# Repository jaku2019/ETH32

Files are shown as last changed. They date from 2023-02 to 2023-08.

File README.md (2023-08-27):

# Supla powered ETH32 light coontroller
Thanks to the amazing help of @elmaya @radzik_r @klew and othher forum.supla.org users I managed to create ETH32 light controller.

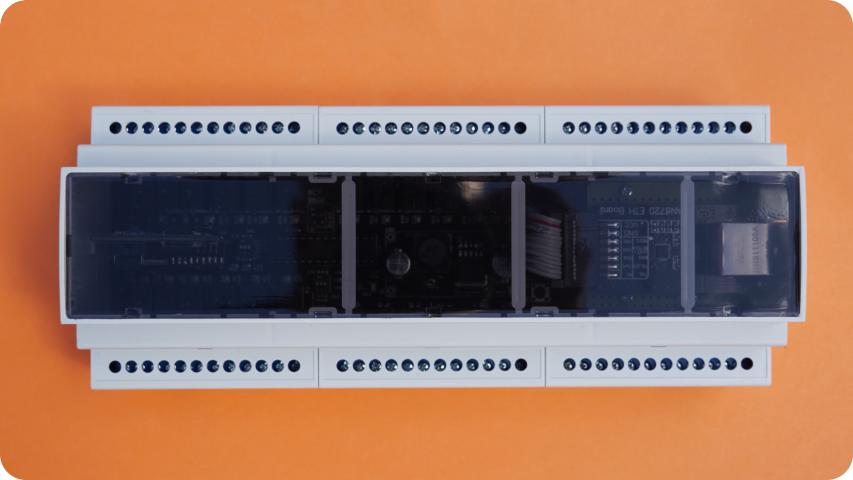
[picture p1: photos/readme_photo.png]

## Main characteristics
- 17 230V inputs (in the photo sample: 16x230V 1x12V) [PC814]
- 18 230V 5A inputs [HF46F/12V]
- TEST button that turns on all the relays (you can change that function in the code)
- LAN8721
- 2xMCP23017 (there is a possibility to channge its addresses with DIN switches)
- easy-access pins: 3,3V, 5V, GND, IO12, IO15, IO35, IO36, IO39, IO0, RX, TX
- easy access to I2C pins
- MCP9808 temperature sensor (there is a possibility to channge its address with DIN switch)
- RTC clock DS3231
- FRAM memory MB85RC256V (there is a possibility to channge its address with DIN switch)

## Info
Instead of soldering the buck converter elements to the PCB, you can insert a ready module LM2596 (it is necessary to set its output voltage to 5V)

ESP is connected with IO by MCP23017. One of this modules was placed on a card that is a bit loose. You shouldn't play with it when ETH32 is on, as it could make the relays stop working. Repositioning it to 90 degrees should solve the problem.

The PCB is designed to fit perfectly in the Kradex ZD1012 enclosure for DIN rail.
## The code
In the software example relays no. 101-116 have assigned inputs with relative numbers. 

Input no. 117 turns on all the relays.
Single click = turn on (all),
double click = turn off (all). 

Everything is preperad to work with monostable buttons. 

There is no thermometer, FRAM memory nor RTC support yet.
## Smart home control
You need to set your Supla accunt mail and server address in the coode (relative fields are placed in the bottom of the code).

You can integrate Supla with e.g. Home Assistant via MQTT. The setup is pretty easy and reliable. https://en-forum.supla.org/viewtopic.php?t=10419

## On the din rail
And that's how it ended! 

You can download a Word file, where you can find ready labels to stick on the enclosure.
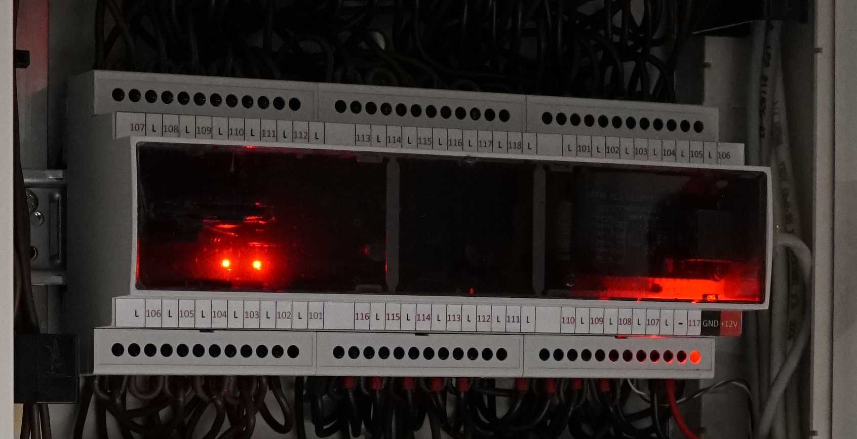
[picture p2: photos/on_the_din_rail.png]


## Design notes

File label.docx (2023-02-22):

| 107 | L | 108 | L | 109 | L | 110 | L | 111 | L | 112 | L | | 113 | L | 114 | L | 115 | L | 116 | L | 117 | L | 118 | L | | L | 101 | L | 102 | L | 103 | L | 104 | L | 105 | L | 106

| L | 106 | L | 105 | L | 104 | L | 103 | L | 102 | L | 101 | | 116 | L | 115 | L | 114 | L | 113 | L | 112 | L | 111 | L | | 110 | L | 109 | L | 108 | L | 107 | L | - | 117 | GND | +12V

| 207 | L | 208 | L | 209 | L | 210 | L | 211 | L | 212 | L | | 213 | L | 214 | L | 215 | L | 216 | L | 217 | L | 218 | L | | L | 201 | L | 202 | L | 203 | L | 204 | L | 205 | L | 206

| L | 206 | L | 205 | L | 204 | L | 203 | L | 202 | L | 201 | | 216 | L | 215 | L | 214 | L | 213 | L | 212 | L | 211 | L | | 210 | L | 209 | L | 208 | L | 207 | L | - | 217 | GND | +12V

| 107 | L | 108 | L | 109 | L | 110 | L | 111 | L | 112 | L | | 113 | L | 114 | L | 115 | L | 116 | L | 117 | L | 118 | L | | L | 101 | L | 102 | L | 103 | L | 104 | L | 105 | L | 106

| L | 106 | L | 105 | L | 104 | L | 103 | L | 102 | L | 101 | | 116 | L | 115 | L | 114 | L | 113 | L | 112 | L | 111 | L | | 110 | L | 109 | L | 108 | L | 107 | L | - | 117 | GND | +12V

| 207 | L | 208 | L | 209 | L | 210 | L | 211 | L | 212 | L | | 213 | L | 214 | L | 215 | L | 216 | L | 217 | L | 218 | L | | L | 201 | L | 202 | L | 203 | L | 204 | L | 205 | L | 206

| L | 206 | L | 205 | L | 204 | L | 203 | L | 202 | L | 201 | | 216 | L | 215 | L | 214 | L | 213 | L | 212 | L | 211 | L | | 210 | L | 209 | L | 208 | L | 207 | L | - | 217 | GND | +12V

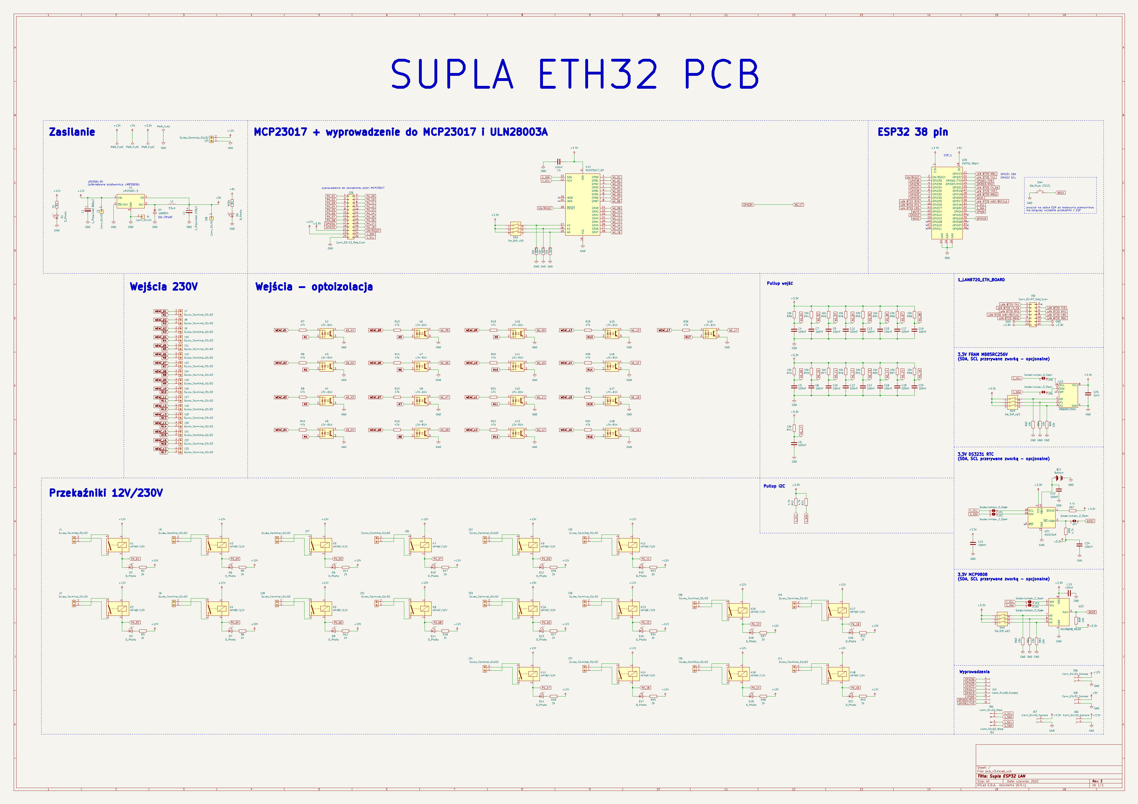
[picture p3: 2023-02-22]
photos/schematic.png

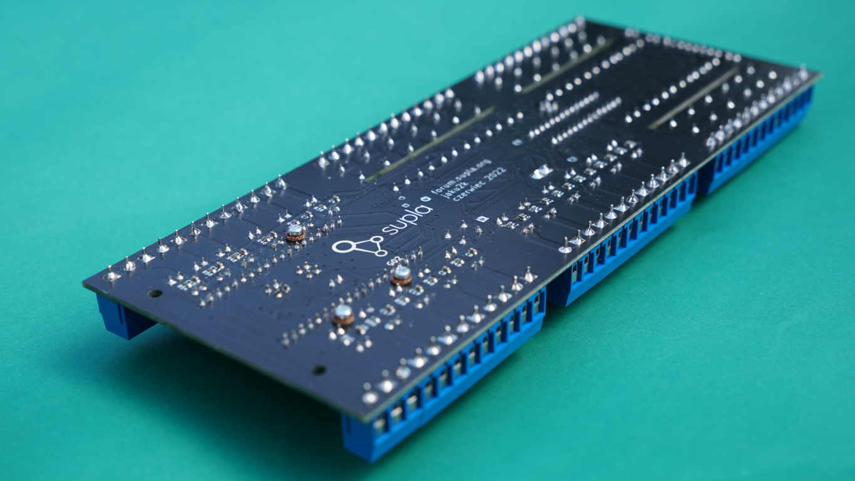
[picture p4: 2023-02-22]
photos/ETH32_photo (9).png

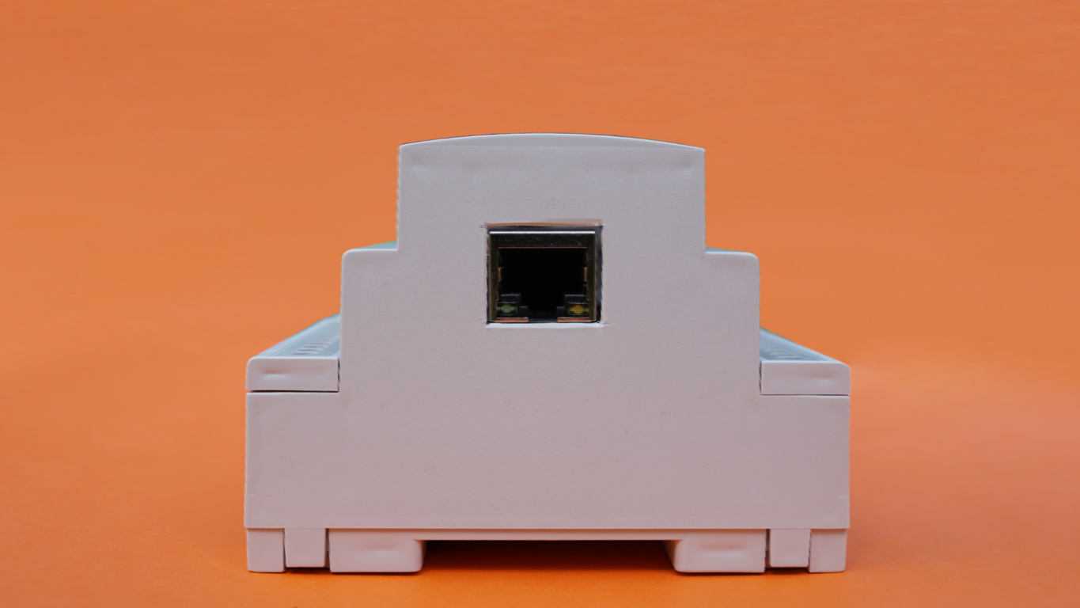
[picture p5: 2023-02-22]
photos/ETH32_photo (5).png

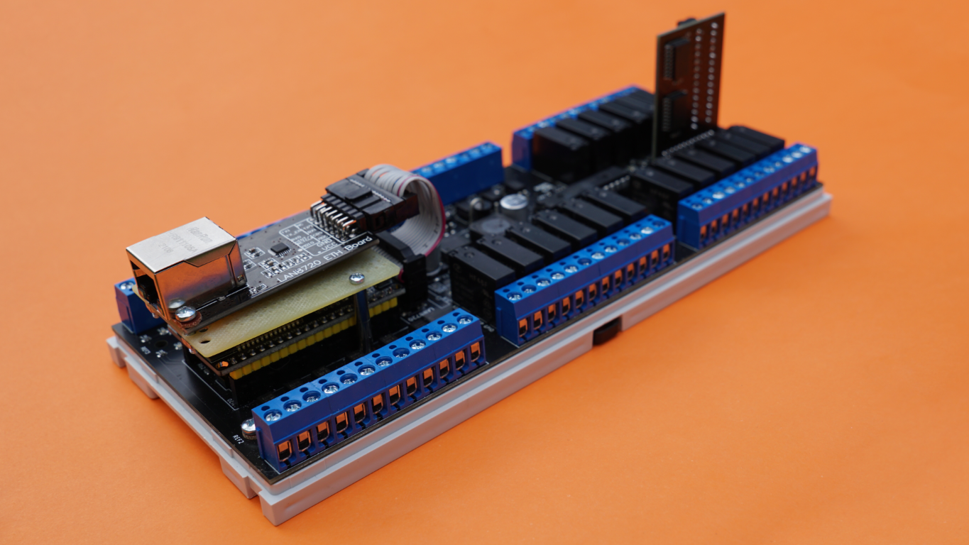
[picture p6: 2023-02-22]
photos/ETH32_photo (1).png

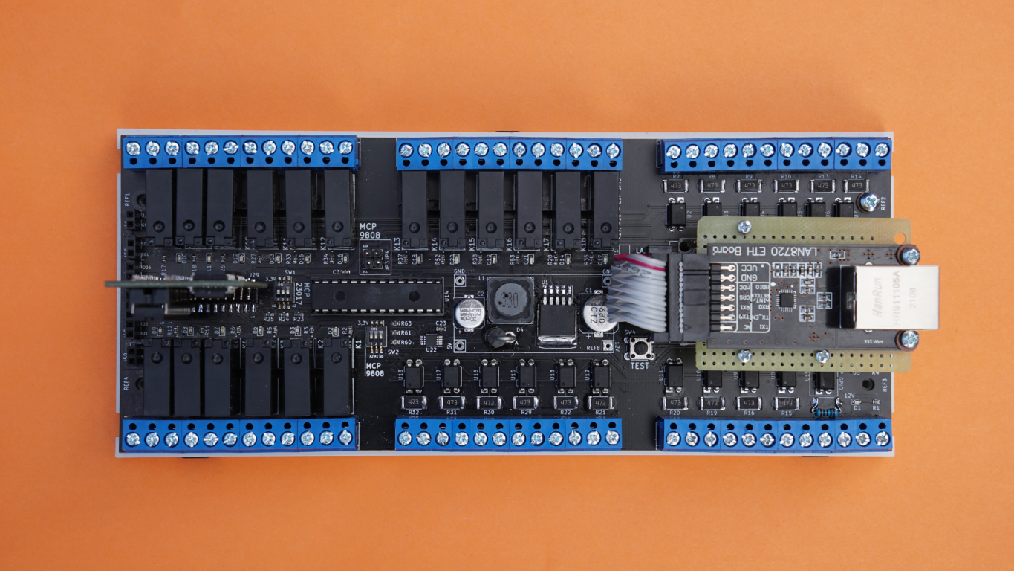
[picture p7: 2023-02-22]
photos/ETH32_photo (3).png

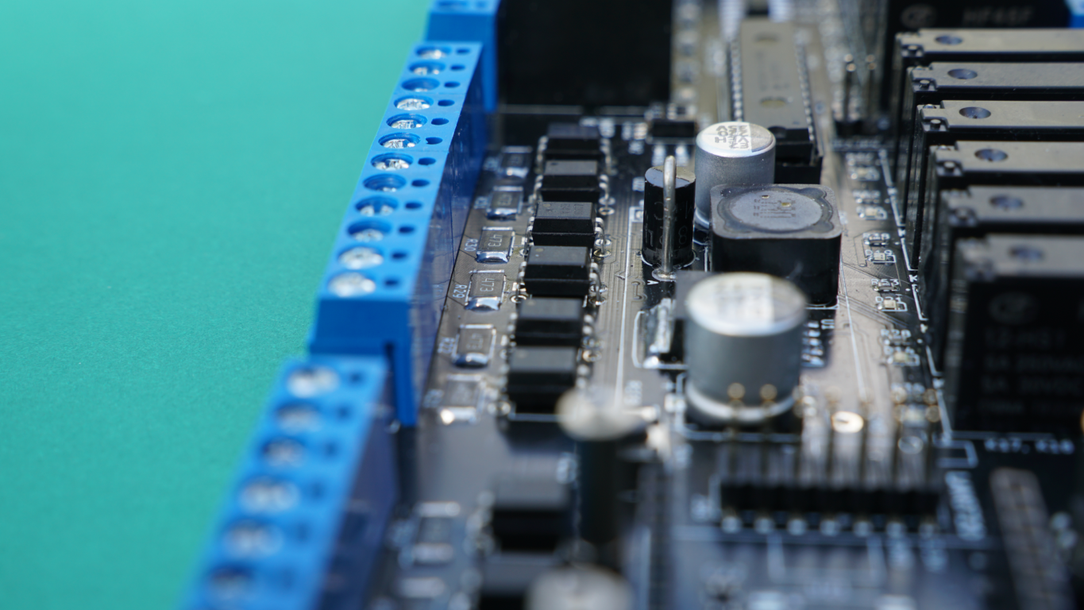
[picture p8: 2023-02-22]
photos/ETH32_photo (10).png

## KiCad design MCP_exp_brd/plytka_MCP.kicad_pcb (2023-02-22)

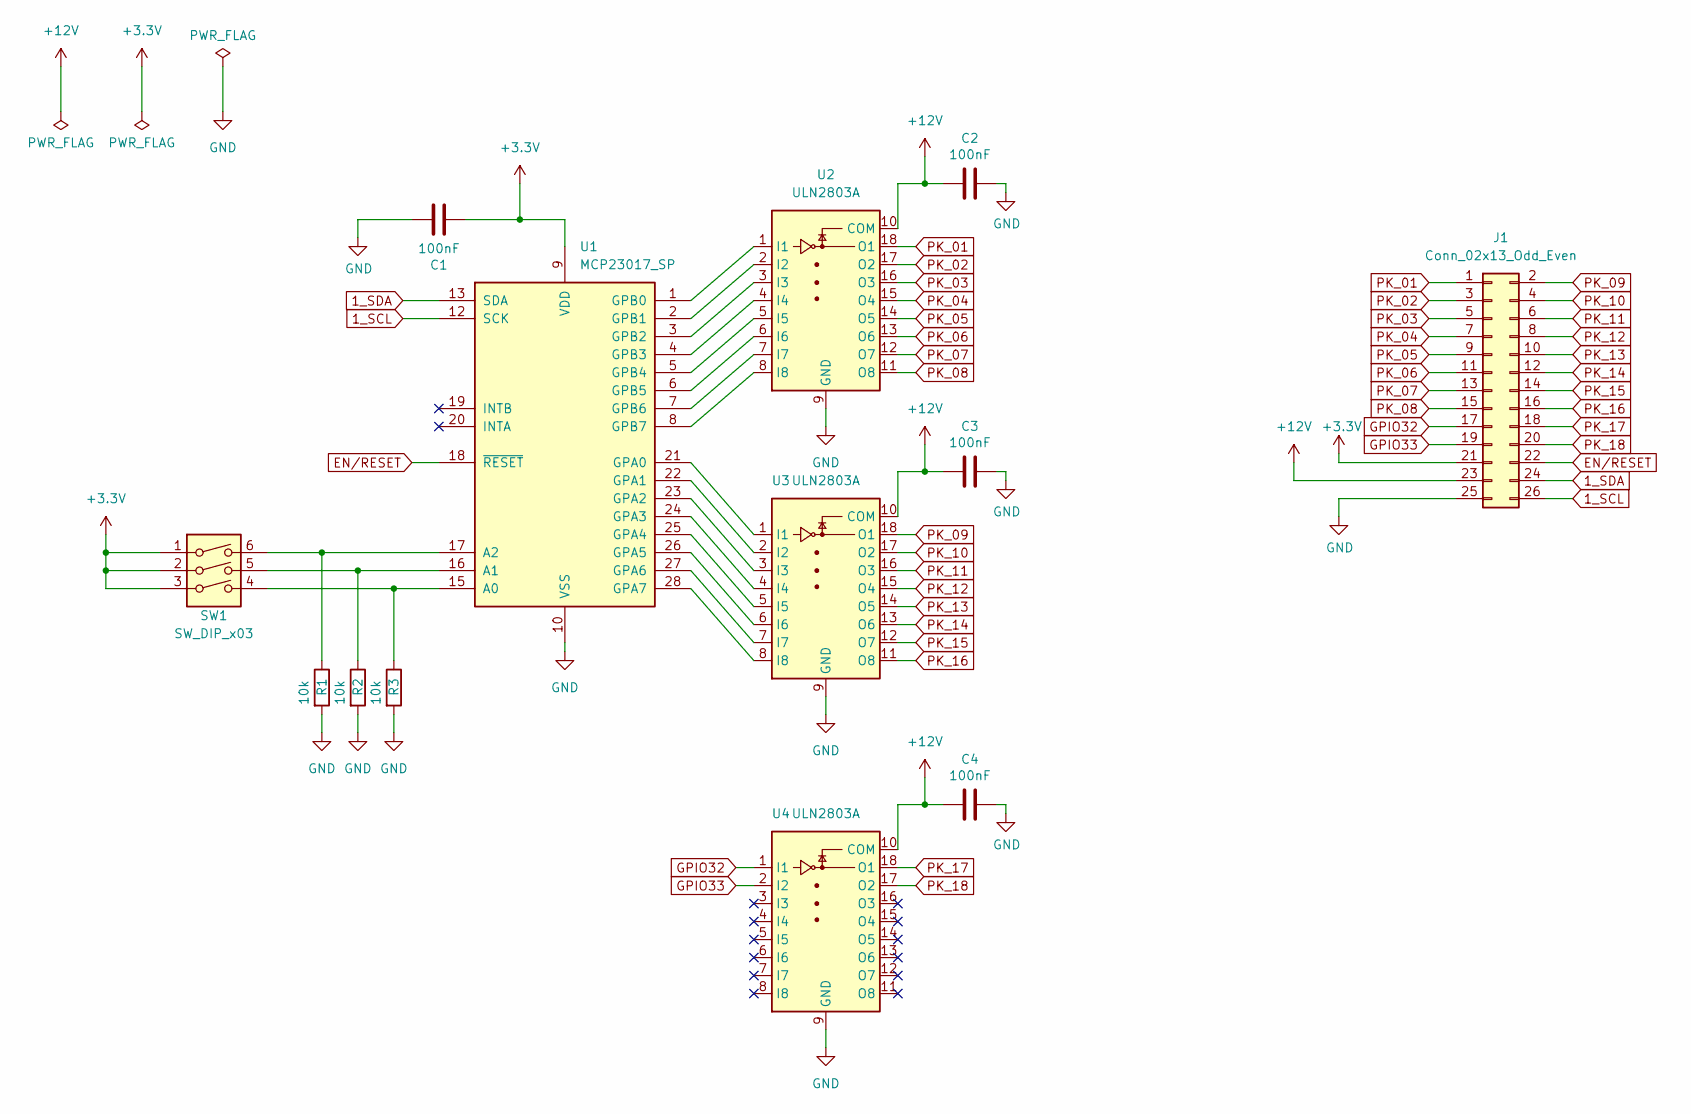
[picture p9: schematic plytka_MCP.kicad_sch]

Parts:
C1, C2, C3, C4: 100nF; C_0603_1608Metric; JLCPCB C14663
J1: Conn_02x13_Odd_Even; PinHeader_2x13_P2.00mm_Horizontal; JLCPCB C2883270
R1, R2, R3: 10k; R_0603_1608Metric; JLCPCB C238881
SW1: SW_DIP_x03; SW_DIP_SPSTx03_Slide_KingTek_DSHP03TS_W7.62mm_P1.27mm; JLCPCB C319051
U1: MCP23017_SP; DIP-28_W7.62mm_Socket; JLCPCB C16653
U2, U3, U4: ULN2803A; SOIC-18W_7.5x11.6mm_P1.27mm; JLCPCB C845537

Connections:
1_SCL: J1.26, U1.12 (SCK)
1_SDA: J1.24, U1.13 (SDA)
+3V3: C1.2, J1.21, SW1.1, SW1.2, SW1.3, U1.9 (VDD)
+12V: C2.2, C3.2, C4.2, J1.23, U2.10 (COM), U3.10 (COM), U4.10 (COM)
EN/RESET: J1.22, U1.18 (~RESET)
GND: C1.1, C2.1, C3.1, C4.1, J1.25, R1.2, R2.2, R3.2, U1.10 (VSS), U2.9 (GND), U3.9 (GND), U4.9 (GND)
GPIO32: J1.17, U4.1 (I1)
GPIO33: J1.19, U4.2 (I2)
unnamed: R1.1, SW1.6, U1.17 (A2)
unnamed: R2.1, SW1.5, U1.16 (A1)
unnamed: R3.1, SW1.4, U1.15 (A0)
unnamed: U1.1 (GPB0), U2.1 (I1)
unnamed: U1.2 (GPB1), U2.2 (I2)
unnamed: U1.3 (GPB2), U2.3 (I3)
unnamed: U1.4 (GPB3), U2.4 (I4)
unnamed: U1.5 (GPB4), U2.5 (I5)
unnamed: U1.6 (GPB5), U2.6 (I6)
unnamed: U1.7 (GPB6), U2.7 (I7)
unnamed: U1.8 (GPB7), U2.8 (I8)
unnamed: U1.21 (GPA0), U3.1 (I1)
unnamed: U1.22 (GPA1), U3.2 (I2)
unnamed: U1.23 (GPA2), U3.3 (I3)
unnamed: U1.24 (GPA3), U3.4 (I4)
unnamed: U1.25 (GPA4), U3.5 (I5)
unnamed: U1.26 (GPA5), U3.6 (I6)
unnamed: U1.27 (GPA6), U3.7 (I7)
unnamed: U1.28 (GPA7), U3.8 (I8)
PK_01: J1.1, U2.18 (O1)
PK_02: J1.3, U2.17 (O2)
PK_03: J1.5, U2.16 (O3)
PK_04: J1.7, U2.15 (O4)
PK_05: J1.9, U2.14 (O5)
PK_06: J1.11, U2.13 (O6)
PK_07: J1.13, U2.12 (O7)
PK_08: J1.15, U2.11 (O8)
PK_09: J1.2, U3.18 (O1)
PK_10: J1.4, U3.17 (O2)
PK_11: J1.6, U3.16 (O3)
PK_12: J1.8, U3.15 (O4)
PK_13: J1.10, U3.14 (O5)
PK_14: J1.12, U3.13 (O6)
PK_15: J1.14, U3.12 (O7)
PK_16: J1.16, U3.11 (O8)
PK_17: J1.18, U4.18 (O1)
PK_18: J1.20, U4.17 (O2)

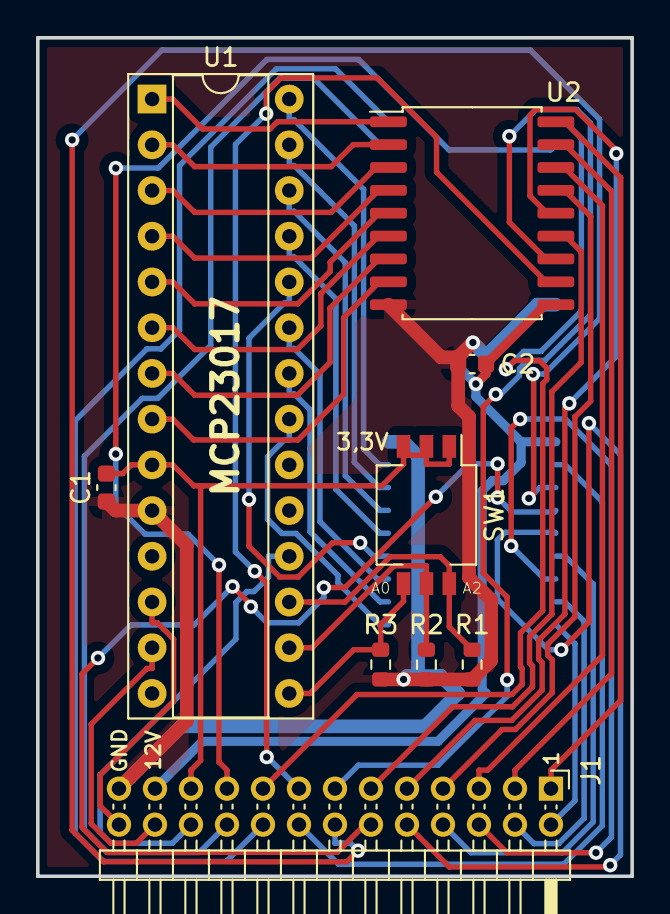
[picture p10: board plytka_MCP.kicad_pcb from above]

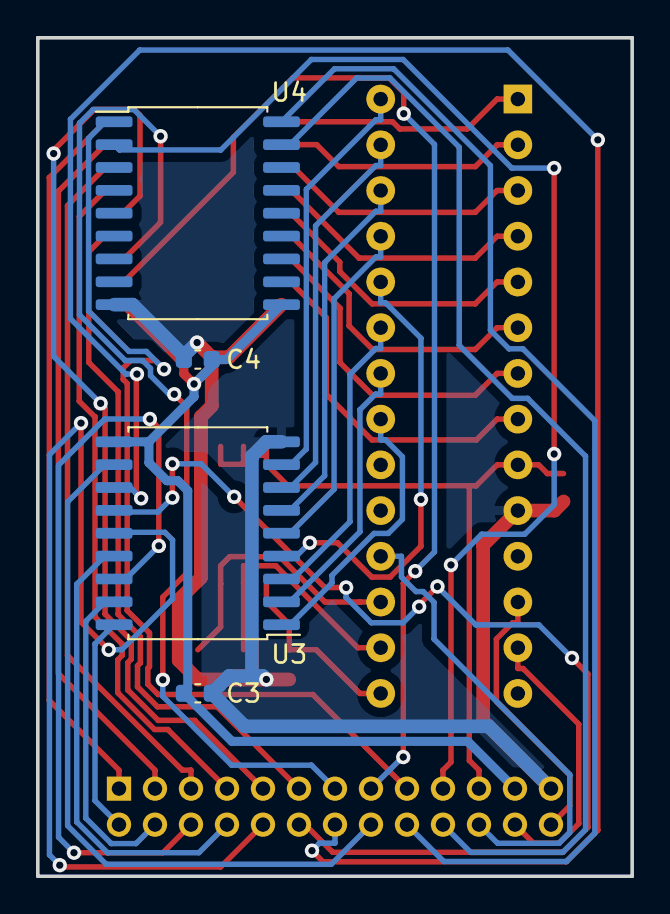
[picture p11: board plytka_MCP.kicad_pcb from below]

Board: 2 copper layers, 33.0 x 46.6 mm, 13 parts (4 on the bottom side), 45 nets.

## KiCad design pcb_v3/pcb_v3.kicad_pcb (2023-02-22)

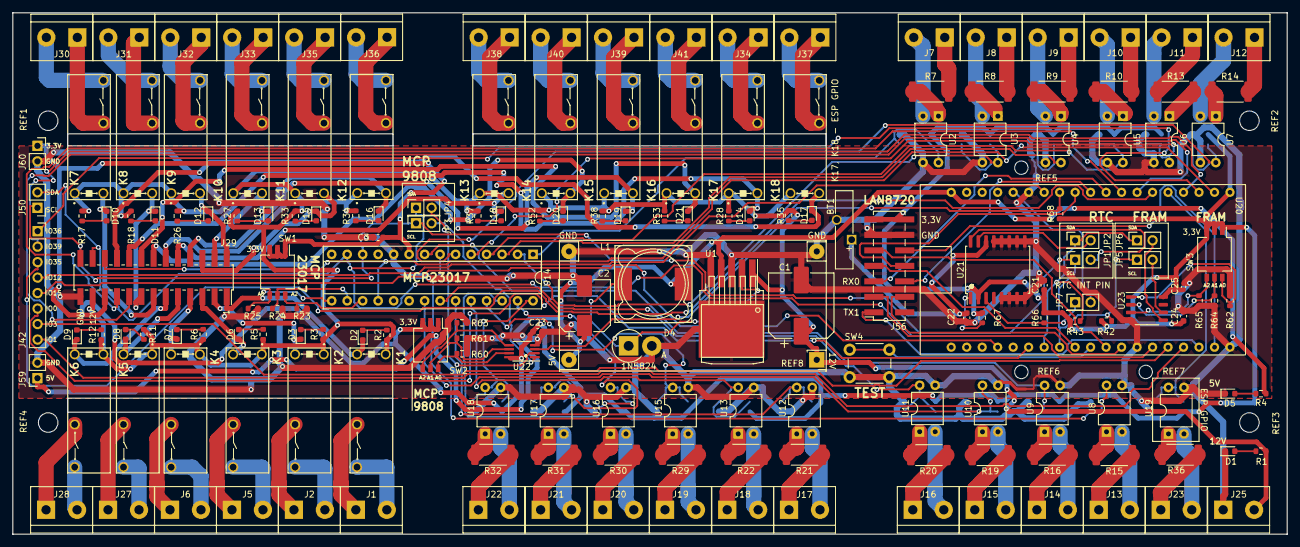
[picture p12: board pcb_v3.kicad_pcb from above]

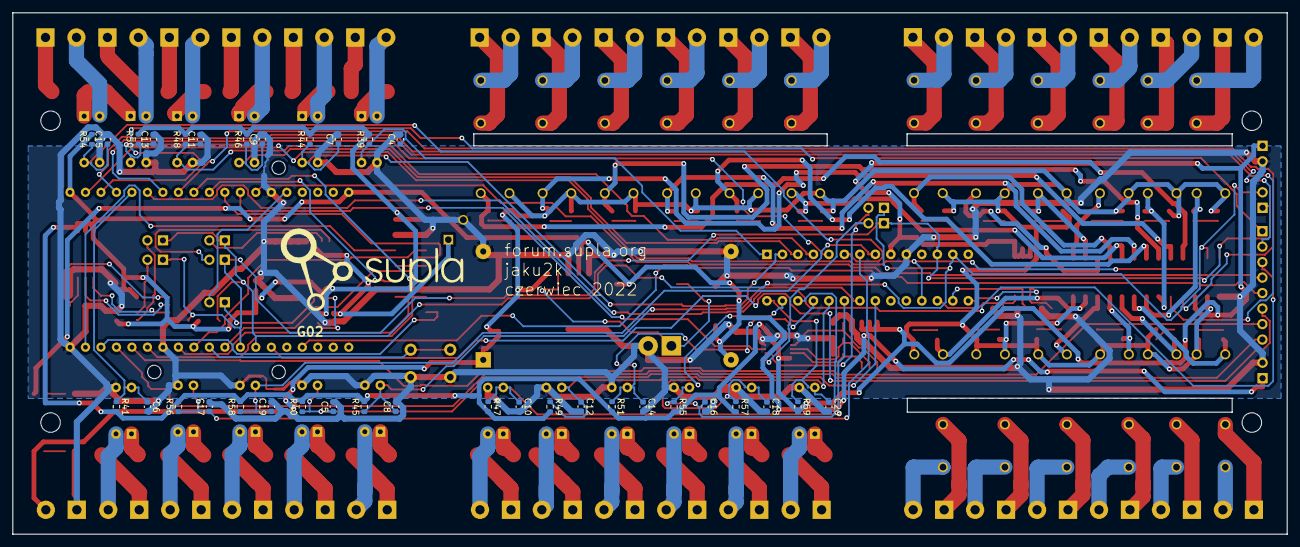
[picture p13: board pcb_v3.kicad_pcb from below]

Board: 2 copper layers, 209.0 x 85.5 mm, 219 parts (35 on the bottom side), 190 nets.

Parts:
BT1: Battery; Battery_Panasonic_CR1220-VCN_Vertical_CircularHoles
C1: C_Polarized 680μF; CP_Elec_10x10.5
C2: C_Polarized 220μF; CP_Elec_8x10
C3, C4, C5, C6, C7, C8, C9, C10, C11, C12, C13, C14, C15, C16, C17, C18, C19, C20, C21, C22, C23, C24: 100nF; C_0603_1608Metric
C25: 10nF; C_0402_1005Metric
D1, D2, D3, D5, D6, D7, D8, D9, D10, D11, D12, D13, D14, D15, D16, D17, D18, D19, D20, D21: D_Photo; LED_0603_1608Metric
D4: 1N5824; D_DO-201AD_P3.81mm_Vertical_AnodeUp
G02: LOGO; supla_logo_3cm
J1, J2, J5, J6, J7, J8, J9, J10, J11, J12, J13, J14, J15, J16, J17, J18, J19, J20, J21, J22, J23, J25, J27, J28, J30, J31, J32, J33, J34, J35, J36, J37, J38, J39, J40, J41: Screw_Terminal_01x02; TerminalBlock_bornier-2_P5.08mm
J29: Conn_02x13_Odd_Even; PinSocket_2x13_P2.00mm_Vertical_SMD
J42: Conn_01x08_Female; PinSocket_1x08_P2.54mm_Vertical
J50: Conn_01x02_Male; PinHeader_1x02_P2.54mm_Vertical
J56: PinHeader_2x07_P2.54mm_Vertical_SMD
J59, J60: Conn_01x02_Male; PinSocket_1x02_P2.54mm_Vertical
JP1, JP2, JP3, JP4, JP5, JP6, JP7: SolderJumper_2_Open; PinHeader_2x01_P2.54mm_Vertical
K1, K2, K3, K4, K5, K6, K7, K8, K9, K10, K11, K12, K13, K14, K15, K16, K17, K18: HF46F/12V; HF46F
L1: 33μH; L_12x12mm_H8mm
R1, R2, R3, R5, R6, R11, R12, R17, R18, R26, R27, R28, R33, R34, R35, R37, R38, R52, R53: 2k; R_0603_1608Metric
R4: 600k; R_0603_1608Metric
R7, R8, R9, R10, R13, R14, R15, R16, R19, R20, R21, R22, R29, R30, R31, R32, R36: 47k; R_2512_6332Metric
R23, R24, R25, R39, R40, R41, R44, R45, R46, R47, R48, R49, R50, R51, R54, R55, R56, R57, R58, R59, R60, R61, R62, R63, R64, R65, R68: 10k; R_0603_1608Metric
R42, R43, R66, R67: 4,7k; R_0603_1608Metric
REF1, REF2, REF3, REF4: MountingHole_3.2mm_M3
REF5, REF6, REF7: MountingHole_2.2mm_M2_ISO14580
REF8: YAAJ_DCDC_StepDown_LM2596
SW1, SW2, SW3: SW_DIP_x03; SW_DIP_SPSTx03_Slide_KingTek_DSHP03TS_W7.62mm_P1.27mm
SW4: SW_Push (TEST); SW_PUSH_6mm_H5mm
U1: LM2596T-5; TO-263-5_TabPin3
U2, U3, U4, U5, U6, U7, U8, U9, U10, U11, U12, U13, U15, U16, U17, U18, U19: LTV-814; DIP-4_W7.62mm
U14: MCP23017_SP; DIP-28_W7.62mm_Socket
U20: ESP32_38pin
U21: DS3231M; SOIC-16W_7.5x10.3mm_P1.27mm
U22: MCP9808_MSOP; MSOP-8_3x3mm_P0.65mm
U23: MB85RC256V; SSOP-8_3.9x5.05mm_P1.27mm

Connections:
1_SCL: J29.26, J50.1, JP1.1 (A), JP3.1 (A), JP5.1 (A), R42.1, U14.12 (SCK), U20.31 (GPIO16)
1_SDA: J29.24, J50.2, JP2.1 (A), JP4.1 (A), JP6.1 (A), R43.1, U14.13 (SDA), U20.32 (GPIO04)
+3V3: C3.2, C21.1, C23.2, C24.1, C25.1, J29.21, J56.13, J56.14, J60.1, R39.2, R40.2, R41.2, R42.2, R43.2, R44.2, R45.2, R46.2, R47.2, R48.2, R49.2, R50.2, R51.2, R54.2, R55.2, R56.2, R57.2, R58.2, R59.2, R66.2, R67.2, R68.2, SW1.1, SW1.2, SW1.3, SW2.1, SW2.2, SW2.3, SW3.1, SW3.2, SW3.3, U14.9 (VDD), U20.1 (3,3V), U21.2 (VCC), U22.8 (VDD), U23.8 (VCC)
+5V: C2.1, J59.1, L1.2, R4.1, REF8.4, U1.4 (FB), U20.19 (5V)
+12V: C1.1, J25.2, J29.23, K1.1, K2.1, K3.1, K4.1, K5.1, K6.1, K7.1, K8.1, K9.1, K10.1, K11.1, K12.1, K13.1, K14.1, K15.1, K16.1, K17.1, K18.1, R1.1, R2.1, R3.1, R5.1, R6.1, R11.1, R12.1, R17.1, R18.1, R26.1, R27.1, R28.1, R33.1, R34.1, R35.1, R37.1, R38.1, R52.1, R53.1, REF8.1, U1.1 (VIN)
EN/RESET: J29.22, U14.18 (~RESET), U20.2 (EN/RESET)
GND: BT1.2 (-), C1.2, C2.2, C3.1, C4.2, C5.2, C6.2, C7.2, C8.2, C9.2, C10.2, C11.2, C12.2, C13.2, C14.2, C15.2, C16.2, C17.2, C18.2, C19.2, C20.2, C21.2, C22.2, C23.1, C24.2, C25.2, D1.1 (K), D4.2 (A), D5.1 (K), J25.1, J29.25, J56.11, J56.12, J59.2, J60.2, R23.2, R24.2, R25.2, R60.2, R61.2, R62.2, R63.2, R64.2, R65.2, REF8.2, REF8.3, SW4.1, U1.3 (GND), U1.5 (~ON/OFF), U2.3, U3.3, U4.3, U5.3, U6.3, U7.3, U8.3, U9.3, U10.3, U11.3, U12.3, U13.3, U14.10 (VSS), U15.3, U16.3, U17.3, U18.3, U19.3, U20.14 (GND), U20.20 (GND), U20.26 (GND), U21.5 (GND), U21.6 (GND), U21.7 (GND), U21.8 (GND), U21.9 (GND), U21.10 (GND), U21.11 (GND), U21.12 (GND), U21.13 (GND), U22.4 (GND), U23.4 (GND)
GPIO0: J42.6, U20.33 (GPIO0)
GPIO01/TX0: J42.8, U20.23 (GPIO01/TX0)
GPIO03/RX0: J42.7, U20.24 (GPIO03/RX0)
GPIO12: J42.4, U20.13 (GPIO12)
GPIO15: J42.5, U20.35 (GPIO15)
GPIO32: J29.17, U20.7 (GPIO32)
GPIO33: J29.19, U20.8 (GPIO33)
GPIO34: C6.1, R41.1, U19.4, U20.5 (GPIO34)
GPIO35: J42.3, U20.6 (GPIO35)
GPIO36: J42.1, U20.3 (GPIO36)
GPIO39: J42.2, U20.4 (GPIO39)
LAN 8720 CRS: J56.8, U20.11 (GPIO27)
LAN 8720 MDC: J56.10, U20.21 (GPIO23)
LAN 8720 MDIO: J56.9, U20.28 (GPIO18)
LAN 8720 RX0: J56.5, U20.9 (GPIO25)
LAN 8720 RX1: J56.6, U20.10 (GPIO26)
LAN 8720 TX0: J56.4, U20.27 (GPIO19)
LAN 8720 TX1: J56.1, U20.22 (GPIO22)
LAN 8720 TX_EN: J56.3, U20.25 (GPIO21)
LAN 8720 nINT/REFCLK: J56.7, U20.30 (GPIO17)
N1: J7.2, U2.2
N2: J8.2, U3.2
N3: J9.2, U4.2
N4: J10.2, U5.2
N5: J11.2, U6.2
N6: J12.2, U7.2
N7: J13.2, U8.2
N8: J14.2, U9.2
N9: J15.2, U10.2
N10: J16.2, U11.2
N11: J17.2, U12.2
N12: J18.2, U13.2
N13: J19.2, U15.2
N14: J20.2, U16.2
N15: J21.2, U17.2
N16: J22.2, U18.2
N17: J23.2, U19.2
unnamed: BT1.1 (+), C22.1, U21.14 (VBAT)
unnamed: D1.2 (A), R1.2
unnamed: D2.2 (A), R2.2
unnamed: D3.2 (A), R3.2
unnamed: D4.1 (K), L1.1, U1.2 (OUT)
unnamed: D5.2 (A), R4.2
unnamed: D6.2 (A), R5.2
unnamed: D7.2 (A), R6.2
unnamed: D8.2 (A), R11.2
unnamed: D9.2 (A), R12.2
unnamed: D10.2 (A), R17.2
unnamed: D11.2 (A), R18.2
unnamed: D12.2 (A), R26.2
unnamed: D13.2 (A), R27.2
unnamed: D14.2 (A), R28.2
unnamed: D15.2 (A), R33.2
unnamed: D16.2 (A), R34.2
unnamed: D17.2 (A), R35.2
unnamed: D18.2 (A), R37.2
unnamed: D19.2 (A), R38.2
unnamed: D20.2 (A), R52.2
unnamed: D21.2 (A), R53.2
unnamed: J1.1, K1.3
unnamed: J1.2, K1.4
unnamed: J2.1, K2.3
unnamed: J2.2, K2.4
unnamed: J5.1, K3.3
unnamed: J5.2, K3.4
unnamed: J6.1, K4.3
unnamed: J6.2, K4.4
unnamed: J27.1, K5.3
unnamed: J27.2, K5.4
unnamed: J28.1, K6.3
unnamed: J28.2, K6.4
unnamed: J30.1, K7.3
unnamed: J30.2, K7.4
unnamed: J31.1, K8.3
unnamed: J31.2, K8.4
unnamed: J32.1, K9.3
unnamed: J32.2, K9.4
unnamed: J33.1, K10.3
unnamed: J33.2, K10.4
unnamed: J34.1, K17.3
unnamed: J34.2, K17.4
unnamed: J35.1, K11.3
unnamed: J35.2, K11.4
unnamed: J36.1, K12.3
unnamed: J36.2, K12.4
unnamed: J37.1, K18.3
unnamed: J37.2, K18.4
unnamed: J38.1, K13.3
unnamed: J38.2, K13.4
unnamed: J39.1, K15.3
unnamed: J39.2, K15.4
unnamed: J40.1, K14.3
unnamed: J40.2, K14.4
unnamed: J41.1, K16.3
unnamed: J41.2, K16.4
unnamed: JP1.2 (B), U21.16 (SCL)
unnamed: JP2.2 (B), U21.15 (SDA)
unnamed: JP3.2 (B), U22.1 (SDA)
unnamed: JP4.2 (B), U22.2 (SCL)
unnamed: JP5.2 (B), U23.6 (SCL)
unnamed: JP6.2 (B), U23.5 (SDA)
unnamed: JP7.1 (A), R66.1, U21.3 (~INT/SQW)
unnamed: R7.2, U2.1
unnamed: R8.2, U3.1
unnamed: R9.2, U4.1
unnamed: R10.2, U5.1
unnamed: R13.2, U6.1
unnamed: R14.2, U7.1
unnamed: R15.2, U8.1
unnamed: R16.2, U9.1
unnamed: R19.2, U10.1
unnamed: R20.2, U11.1
unnamed: R21.2, U12.1
unnamed: R22.2, U13.1
unnamed: R23.1, SW1.6, U14.17 (A2)
unnamed: R24.1, SW1.5, U14.16 (A1)
unnamed: R25.1, SW1.4, U14.15 (A0)
unnamed: R29.2, U15.1
unnamed: R30.2, U16.1
unnamed: R31.2, U17.1
unnamed: R32.2, U18.1
unnamed: R36.2, U19.1
unnamed: R60.1, SW2.6, U22.7 (A0)
unnamed: R61.1, SW2.5, U22.6 (A1)
unnamed: R62.1, SW3.6, U23.1 (A0)
unnamed: R63.1, SW2.4, U22.5 (A2)
unnamed: R64.1, SW3.5, U23.2 (A1)
unnamed: R65.1, SW3.4, U23.3 (A2)
unnamed: R67.1, U21.1 (32KHZ)
PK_01: D2.1 (K), J29.1, K1.2
PK_02: D3.1 (K), J29.3, K2.2
PK_03: D6.1 (K), J29.5, K3.2
PK_04: D7.1 (K), J29.7, K4.2
PK_05: D8.1 (K), J29.9, K5.2
PK_06: D9.1 (K), J29.11, K6.2
PK_07: D10.1 (K), J29.13, K7.2
PK_08: D11.1 (K), J29.15, K8.2
PK_09: D12.1 (K), J29.2, K9.2
PK_10: D13.1 (K), J29.4, K10.2
PK_11: D15.1 (K), J29.6, K11.2
PK_12: D16.1 (K), J29.8, K12.2
PK_13: D18.1 (K), J29.10, K13.2
PK_14: D19.1 (K), J29.12, K15.2
PK_15: D20.1 (K), J29.14, K14.2
PK_16: D21.1 (K), J29.16, K16.2
PK_17: D14.1 (K), J29.18, K17.2
PK_18: D17.1 (K), J29.20, K18.2
WE01: SW4.2, U20.29 (GPIO05)
WE02: JP7.2 (B), U20.15 (GPIO13)
WE03: R68.1, U20.12 (GPIO14), U22.3 (Alert)
WEAC_01: J7.1, R7.1
WEAC_02: J8.1, R8.1
WEAC_03: J9.1, R9.1
WEAC_04: J10.1, R10.1
WEAC_05: J11.1, R13.1
WEAC_06: J12.1, R14.1
WEAC_07: J13.1, R15.1
WEAC_08: J14.1, R16.1
WEAC_09: J15.1, R19.1
WEAC_10: J16.1, R20.1
WEAC_11: J17.1, R21.1
WEAC_12: J18.1, R22.1
WEAC_13: J19.1, R29.1
WEAC_14: J20.1, R30.1
WEAC_15: J21.1, R31.1
WEAC_16: J22.1, R32.1
WEAC_17: J23.1, R36.1
WE_01: C4.1, R39.1, U2.4, U14.1 (GPB0)
WE_02: C7.1, R44.1, U3.4, U14.2 (GPB1)
WE_03: C9.1, R46.1, U4.4, U14.3 (GPB2)
WE_04: C11.1, R48.1, U5.4, U14.4 (GPB3)
WE_05: C13.1, R50.1, U6.4, U14.5 (GPB4)
WE_06: C15.1, R54.1, U7.4, U14.6 (GPB5)
WE_07: C17.1, R56.1, U8.4, U14.7 (GPB6)
WE_08: C19.1, R58.1, U9.4, U14.8 (GPB7)
WE_09: C5.1, R40.1, U10.4, U14.21 (GPA0)
WE_10: C8.1, R45.1, U11.4, U14.22 (GPA1)
WE_11: C10.1, R47.1, U12.4, U14.23 (GPA2)
WE_12: C12.1, R49.1, U13.4, U14.24 (GPA3)
WE_13: C14.1, R51.1, U14.25 (GPA4), U15.4
WE_14: C16.1, R55.1, U14.26 (GPA5), U16.4
WE_15: C18.1, R57.1, U14.27 (GPA6), U17.4
WE_16: C20.1, R59.1, U14.28 (GPA7), U18.4

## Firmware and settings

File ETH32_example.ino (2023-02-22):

/*
  Copyright (C) AC SOFTWARE SP. Z O.O.

  This program is free software; you can redistribute it and/or
  modify it under the terms of the GNU General Public License
  as published by the Free Software Foundation; either version 2
  of the License, or (at your option) any later version.
  This program is distributed in the hope that it will be useful,
  but WITHOUT ANY WARRANTY; without even the implied warranty of
  MERCHANTABILITY or FITNESS FOR A PARTICULAR PURPOSE.  See the
  GNU General Public License for more details.
  You should have received a copy of the GNU General Public License
  along with this program; if not, write to the Free Software
  Foundation, Inc., 59 Temple Place - Suite 330, Boston, MA  02111-1307, USA.
*/

/*
-(50MHz) Osc. Enable to GND -
GPIO22 - EMAC_TXD1   : TX1
GPIO19 - EMAC_TXD0   : TX0
GPIO21 - EMAC_TX_EN  : TX_EN
GPIO26 - EMAC_RXD1   : RX1
GPIO25 - EMAC_RXD0   : RX0
GPIO27 - EMAC_RX_DV  : CRS
GPIO17 - EMAC_TX_CLK : nINT/REFCLK (50MHz)
GPIO23 - SMI_MDC     : MDC
GPIO18 - SMI_MDIO    : MDIO
GND                  : GND
3V3                  : VCC
*/

#define supla_lib_config_h_  // silences debug messages
#define STATUS_LED_GPIO 22

#include <SuplaDevice.h>
#include <Adafruit_MCP23017.h>
#include <SPI.h>
#include <supla/io.h>
#include <supla/control/relay.h>
#include <supla/control/button.h>
#include <supla/control/action_trigger.h>
#include <supla/network/esp32eth.h>
  Supla::ESPETH Eth(1);  // uint_t ETH_ADDR = I²C-address of Ethernet PHY (0 or 1)


Adafruit_MCP23017 mcp; // adds supprt for two MCP, based on examples shared by @elmaya i @radzik_r: https://forum.supla.org/viewtopic.php?p=79452#p79452
Adafruit_MCP23017 mcp2;

class MyMcp23017 : public Supla::Io {
  public:
    void customDigitalWrite(int channelNumber, uint8_t pin, uint8_t val) {
      if ((pin >= 100) && (pin <= 115)) {
        mcp.digitalWrite(pin - 100, val);
               return;
      }
      if (pin <= 99) {
        return ::digitalWrite(pin, val);
      }
    }

    int customDigitalRead(int channelNumber, uint8_t pin) {
      if ((pin >= 100) && (pin <= 115)) {
        return mcp.digitalRead(pin - 100);
      }
      if (pin <= 99) {
        return ::digitalRead(pin);
      }
      if ((pin >= 200) && (pin <= 215)) {
        return mcp2.digitalRead(pin - 200);
      }
    }
} MyMcp23017;

 
 void setup() {
  Serial.begin(115200);
    Wire.begin(4,16); //Wire.begin (sda, scl)
    mcp.begin();  // sets MCP to 0x20
   
  mcp.pinMode(0, OUTPUT);
  mcp.pinMode(1, OUTPUT);
  mcp.pinMode(2, OUTPUT);
  mcp.pinMode(3, OUTPUT);
  mcp.pinMode(4, OUTPUT);
  mcp.pinMode(5, OUTPUT);
  mcp.pinMode(6, OUTPUT);
  mcp.pinMode(7, OUTPUT);
  mcp.pinMode(8, OUTPUT);
  mcp.pinMode(9, OUTPUT);
  mcp.pinMode(10, OUTPUT);
  mcp.pinMode(11, OUTPUT);
  mcp.pinMode(12, OUTPUT);
  mcp.pinMode(13, OUTPUT);
  mcp.pinMode(14, OUTPUT);
  mcp.pinMode(15, OUTPUT);
  
    mcp2.begin(1);  // sets MCP2 to 0x21
     
  mcp2.pinMode(0, INPUT);  mcp2.pullUp(0, HIGH);  // turn on a 100K true internally
  mcp2.pinMode(1, INPUT);  mcp2.pullUp(1, HIGH);  // turn on a 100K true internally
  mcp2.pinMode(2, INPUT);  mcp2.pullUp(2, HIGH);  // turn on a 100K true internally
  mcp2.pinMode(3, INPUT);  mcp2.pullUp(3, HIGH);  // turn on a 100K true internally
  mcp2.pinMode(4, INPUT);  mcp2.pullUp(4, HIGH);  // turn on a 100K true internally
  mcp2.pinMode(5, INPUT);  mcp2.pullUp(5, HIGH);  // turn on a 100K true internally
  mcp2.pinMode(6, INPUT);  mcp2.pullUp(6, HIGH);  // turn on a 100K true internally
  mcp2.pinMode(7, INPUT);  mcp2.pullUp(7, HIGH);  // turn on a 100K true internally
  mcp2.pinMode(8, INPUT);  mcp2.pullUp(8, HIGH);  // turn on a 100K true internally
  mcp2.pinMode(9, INPUT);  mcp2.pullUp(9, HIGH);  // turn on a 100K true internally
  mcp2.pinMode(10, INPUT);  mcp2.pullUp(10, HIGH);  // turn on a 100K true internally
  mcp2.pinMode(11, INPUT);  mcp2.pullUp(11, HIGH);  // turn on a 100K true internally
  mcp2.pinMode(12, INPUT);  mcp2.pullUp(12, HIGH);  // turn on a 100K true internally
  mcp2.pinMode(13, INPUT);  mcp2.pullUp(13, HIGH);  // turn on a 100K true internally
  mcp2.pinMode(14, INPUT);  mcp2.pullUp(14, HIGH);  // turn on a 100K true internally
  mcp2.pinMode(15, INPUT);  mcp2.pullUp(15, HIGH);  // turn on a 100K true internally
  
  // Replace the falowing GUID with value that you can retrieve from https://www.supla.org/arduino/get-guid
  char GUID[SUPLA_GUID_SIZE] = {0x30,0x65,0x52,0x02,0x2A,0xF9,0x53,0x46,0xF6,0x21,0xC9,0x72,0xD6,0x3C,0xDD,0x20};

  // Replace the following AUTHKEY with value that you can retrieve from: https://www.supla.org/arduino/get-authkey
  char AUTHKEY[SUPLA_AUTHKEY_SIZE] = {0x84,0x83,0x4F,0x2F,0x73,0x00,0x82,0xD2,0x29,0x24,0xE6,0x2E,0x04,0xDC,0xDD,0x9B};

  // Sekcja mapowania przekaźników i przycisków; przekaźniki: https://forum.supla.org/viewtopic.php?t=7263; przyciski: https://forum.supla.org/viewtopic.php?t=7512; wyzwalacze akcji: https://forum.supla.org/viewtopic.php?t=9503
  
  auto r101 = new Supla::Control::Relay(108); //B0
  auto r102 = new Supla::Control::Relay(109); //B1
  auto r103 = new Supla::Control::Relay(110); //B2
  auto r104 = new Supla::Control::Relay(111); //B3
  auto r105 = new Supla::Control::Relay(112); //B4
  auto r106 = new Supla::Control::Relay(113); //B5
  auto r107 = new Supla::Control::Relay(114); //B6
  auto r108 = new Supla::Control::Relay(115); //B7
  auto r109 = new Supla::Control::Relay(100); //A0
  auto r110 = new Supla::Control::Relay(101); //A1
  auto r111 = new Supla::Control::Relay(102); //A2
  auto r112 = new Supla::Control::Relay(103); //A3
  auto r113 = new Supla::Control::Relay(104); //A4
  auto r114 = new Supla::Control::Relay(106); //A6
  auto r115 = new Supla::Control::Relay(105); //A5
  auto r116 = new Supla::Control::Relay(107); //A7
  auto r117 = new Supla::Control::Relay(32);  //IO32
  auto r118 = new Supla::Control::Relay(33);  //IO33

  auto b101 = new Supla::Control::Button(208, true, true); // input pullup and reverse logic (connects to GND) B0
  auto b102 = new Supla::Control::Button(209, true, true); // input pullup and reverse logic (connects to GND) B1
  auto b103 = new Supla::Control::Button(210, true, true); // input pullup and reverse logic (connects to GND) B2
  auto b104 = new Supla::Control::Button(211, true, true); // input pullup and reverse logic (connects to GND) B3
  auto b105 = new Supla::Control::Button(212, true, true); // input pullup and reverse logic (connects to GND) B4
  auto b106 = new Supla::Control::Button(213, true, true); // input pullup and reverse logic (connects to GND) B5
  auto b107 = new Supla::Control::Button(214, true, true); // input pullup and reverse logic (connects to GND) B6
  auto b108 = new Supla::Control::Button(215, true, true); // input pullup and reverse logic (connects to GND) B7
  auto b109 = new Supla::Control::Button(200, true, true); // input pullup and reverse logic (connects to GND) A0
  auto b110 = new Supla::Control::Button(201, true, true); // input pullup and reverse logic (connects to GND) A1
  auto b111 = new Supla::Control::Button(202, true, true); // input pullup and reverse logic (connects to GND) A2
  auto b112 = new Supla::Control::Button(203, true, true); // input pullup and reverse logic (connects to GND) A3
  auto b113 = new Supla::Control::Button(204, true, true); // input pullup and reverse logic (connects to GND) A4
  auto b114 = new Supla::Control::Button(205, true, true); // input pullup and reverse logic (connects to GND) A5
  auto b115 = new Supla::Control::Button(206, true, true); // input pullup and reverse logic (connects to GND) A6
  auto b116 = new Supla::Control::Button(207, true, true); // input pullup and reverse logic (connects to GND) A7
  auto b117 = new Supla::Control::Button(34, true, true); // input pullup and reverse logic (connects to GND)  IO34
  auto b118 = new Supla::Control::Button(5, true, true); // input pullup and reverse logic (connects to GND)  IO5
  b118->setMulticlickTime(400); // the software counts clicks and after 400ms after the release of a button starts an predefined action
  b118->setHoldTime(2000); // after 2s of holding the button the ON_HOLD event will be started

  auto at101 = new Supla::Control::ActionTrigger();
  at101->setRelatedChannel(r101);  // pairs the AT with relay channel in Supla Cloud
  at101->attach(b101);
  b101->setMulticlickTime(400, false); // true for bistable button
  b101->setHoldTime(2000); // after 2s of holding the button the ON_HOLD event will be started
  auto at102 = new Supla::Control::ActionTrigger();
  at102->setRelatedChannel(r102);  // pairs the AT with relay channel in Supla Cloud
  at102->attach(b102);
  b102->setMulticlickTime(400, false); // true for bistable button
  b102->setHoldTime(2000); // po 2 s od przytrzymania przycisku zostanie wywołane zdarzenie ON_HOLD
  auto at103 = new Supla::Control::ActionTrigger();
  at103->setRelatedChannel(r103);  // pairs the AT with relay channel in Supla Cloud
  at103->attach(b103);
  b103->setMulticlickTime(400, false); // true for bistable button
  b103->setHoldTime(2000); // after 2s of holding the button the ON_HOLD event will be started
  auto at104 = new Supla::Control::ActionTrigger();
  at104->setRelatedChannel(r104);  // pairs the AT with relay channel in Supla Cloud
  at104->attach(b104);
  b104->setMulticlickTime(400, false); // true for bistable button
  b104->setHoldTime(2000); // after 2s of holding the button the ON_HOLD event will be started
  auto at105 = new Supla::Control::ActionTrigger();
  at105->setRelatedChannel(r105);  // pairs the AT with relay channel in Supla Cloud
  at105->attach(b105);
  b105->setMulticlickTime(400, false); // true for bistable button
  b105->setHoldTime(2000); // after 2s of holding the button the ON_HOLD event will be started
  auto at106 = new Supla::Control::ActionTrigger();
  at106->setRelatedChannel(r106);  // pairs the AT with relay channel in Supla Cloud
  at106->attach(b106);
  b106->setMulticlickTime(400, false); // true for bistable button
  b106->setHoldTime(2000); // after 2s of holding the button the ON_HOLD event will be started
  auto at107 = new Supla::Control::ActionTrigger();
  at107->setRelatedChannel(r107);  // pairs the AT with relay channel in Supla Cloud
  at107->attach(b107);
  b107->setMulticlickTime(400, false); // true for bistable button
  b107->setHoldTime(2000); // after 2s of holding the button the ON_HOLD event will be started
  auto at108 = new Supla::Control::ActionTrigger();
  at108->setRelatedChannel(r108);  // pairs the AT with relay channel in Supla Cloud
  at108->attach(b108);
  b108->setMulticlickTime(400, false); // true for bistable button
  b108->setHoldTime(2000); // after 2s of holding the button the ON_HOLD event will be started
  auto at109 = new Supla::Control::ActionTrigger();
  at109->setRelatedChannel(r109);  // pairs the AT with relay channel in Supla Cloud
  at109->attach(b109);
  b109->setMulticlickTime(400, false); // true for bistable button
  b109->setHoldTime(2000); // after 2s of holding the button the ON_HOLD event will be started
  auto at110 = new Supla::Control::ActionTrigger();
  at110->setRelatedChannel(r110);  // pairs the AT with relay channel in Supla Cloud
  at110->attach(b110);
  b110->setMulticlickTime(400, false); // true for bistable button
  b110->setHoldTime(2000); // after 2s of holding the button the ON_HOLD event will be started
  auto at111 = new Supla::Control::ActionTrigger();
  at111->setRelatedChannel(r111);  // pairs the AT with relay channel in Supla Cloud
  at111->attach(b111);
  b111->setMulticlickTime(400, false); // true for bistable button
  b111->setHoldTime(2000); // after 2s of holding the button the ON_HOLD event will be started
  auto at112 = new Supla::Control::ActionTrigger();
  at112->setRelatedChannel(r112);  // pairs the AT with relay channel in Supla Cloud
  at112->attach(b112);
  b112->setMulticlickTime(400, false); // true for bistable button
  b112->setHoldTime(2000); // after 2s of holding the button the ON_HOLD event will be started
  auto at113 = new Supla::Control::ActionTrigger();
  at113->setRelatedChannel(r113);  // pairs the AT with relay channel in Supla Cloud
  at113->attach(b113);
  b113->setMulticlickTime(400, false); // true for bistable button
  b113->setHoldTime(2000); // after 2s of holding the button the ON_HOLD event will be started
  auto at114 = new Supla::Control::ActionTrigger();
  at114->setRelatedChannel(r114);  // pairs the AT with relay channel in Supla Cloud
  at114->attach(b114);
  b114->setMulticlickTime(400, false); // true for bistable button
  b114->setHoldTime(2000); // after 2s of holding the button the ON_HOLD event will be started
  auto at115 = new Supla::Control::ActionTrigger();
  at1155->setRelatedChannel(r115);  // pairs the AT with relay channel in Supla Cloud
  at115->attach(b115);
  b115->setMulticlickTime(400, false); // true for bistable button
  b115->setHoldTime(2000); // after 2s of holding the button the ON_HOLD event will be started
  auto at116 = new Supla::Control::ActionTrigger();
  at116->setRelatedChannel(r116);  // pairs the AT with relay channel in Supla Cloud
  at116->attach(b116);
  b116->setMulticlickTime(400, false); // true for bistable button
  b116->setHoldTime(2000); // after 2s of holding the button the ON_HOLD event will be started
  auto at117 = new Supla::Control::ActionTrigger();
  at117->setRelatedChannel(r117);  // pairs the AT with relay channel in Supla Cloud
  at117->attach(b117);
  b117->setMulticlickTime(400, false); // true for bistable button
  b117->setHoldTime(2000); // after 2s of holding the button the ON_HOLD event will be started
  auto at118 = new Supla::Control::ActionTrigger();
  at118->attach(b118);
    
  // You can find more about pairing buttons with relays on the forum: https://forum.supla.org/viewtopic.php?t=7512

  b101->addAction(Supla::TOGGLE , r101, Supla::ON_PRESS); // 1
  b102->addAction(Supla::TOGGLE , r102, Supla::ON_PRESS); // 2
  b103->addAction(Supla::TOGGLE , r103, Supla::ON_PRESS); // 3
  b104->addAction(Supla::TOGGLE , r104, Supla::ON_PRESS); // 4
  b105->addAction(Supla::TOGGLE , r105, Supla::ON_PRESS); // 5
  b106->addAction(Supla::TOGGLE , r106, Supla::ON_PRESS); // 6
  b107->addAction(Supla::TOGGLE , r107, Supla::ON_PRESS); // 7
  b108->addAction(Supla::TOGGLE , r108, Supla::ON_PRESS); // 8
  b109->addAction(Supla::TOGGLE , r109, Supla::ON_PRESS); // 9  
  b110->addAction(Supla::TOGGLE , r110, Supla::ON_PRESS); // 10
  b111->addAction(Supla::TOGGLE , r111, Supla::ON_PRESS); // 11
  b112->addAction(Supla::TOGGLE , r112, Supla::ON_PRESS); // 12
  b113->addAction(Supla::TOGGLE , r113, Supla::ON_PRESS); // 13
  b114->addAction(Supla::TOGGLE , r114, Supla::ON_PRESS); // 14
  b115->addAction(Supla::TOGGLE , r115, Supla::ON_PRESS); // 15
  b116->addAction(Supla::TOGGLE , r116, Supla::ON_PRESS); // 16

  // turn off all relays
  b117->addAction(Supla::TURN_OFF , r101, Supla::ON_PRESS); // 1
  b117->addAction(Supla::TURN_OFF , r102, Supla::ON_PRESS); // 2
  b117->addAction(Supla::TURN_OFF , r103, Supla::ON_PRESS); // 3
  b117->addAction(Supla::TURN_OFF , r104, Supla::ON_PRESS); // 4
  b117->addAction(Supla::TURN_OFF , r105, Supla::ON_PRESS); // 5
  b117->addAction(Supla::TURN_OFF , r106, Supla::ON_PRESS); // 6
  b117->addAction(Supla::TURN_OFF , r107, Supla::ON_PRESS); // 7
  b117->addAction(Supla::TURN_OFF , r108, Supla::ON_PRESS); // 8
  b117->addAction(Supla::TURN_OFF , r109, Supla::ON_PRESS); // 9
  b117->addAction(Supla::TURN_OFF , r110, Supla::ON_PRESS); // 10
  b117->addAction(Supla::TURN_OFF , r111, Supla::ON_PRESS); // 11
  b117->addAction(Supla::TURN_OFF , r112, Supla::ON_PRESS); // 12
  b117->addAction(Supla::TURN_OFF , r113, Supla::ON_PRESS); // 13
  b117->addAction(Supla::TURN_OFF , r114, Supla::ON_PRESS); // 14
  b117->addAction(Supla::TURN_OFF , r115, Supla::ON_PRESS); // 15
  b117->addAction(Supla::TURN_OFF , r116, Supla::ON_PRESS); // 16
  b117->addAction(Supla::TURN_OFF , r117, Supla::ON_PRESS); // 17
  b117->addAction(Supla::TURN_OFF , r118, Supla::ON_PRESS); // 18

  // test button
  b118->addAction(Supla::TURN_ON , r101, Supla::ON_CLICK_1); // 1
  b118->addAction(Supla::TURN_ON , r102, Supla::ON_CLICK_1); // 2
  b118->addAction(Supla::TURN_ON , r103, Supla::ON_CLICK_1); // 3
  b118->addAction(Supla::TURN_ON , r104, Supla::ON_CLICK_1); // 4
  b118->addAction(Supla::TURN_ON , r105, Supla::ON_CLICK_1); // 5
  b118->addAction(Supla::TURN_ON , r106, Supla::ON_CLICK_1); // 6
  b118->addAction(Supla::TURN_ON , r107, Supla::ON_CLICK_1); // 7
  b118->addAction(Supla::TURN_ON , r108, Supla::ON_CLICK_1); // 8
  b118->addAction(Supla::TURN_ON , r109, Supla::ON_CLICK_1); // 9
  b118->addAction(Supla::TURN_ON , r110, Supla::ON_CLICK_1); // 10
  b118->addAction(Supla::TURN_ON , r111, Supla::ON_CLICK_1); // 11
  b118->addAction(Supla::TURN_ON , r112, Supla::ON_CLICK_1); // 12
  b118->addAction(Supla::TURN_ON , r113, Supla::ON_CLICK_1); // 13
  b118->addAction(Supla::TURN_ON , r114, Supla::ON_CLICK_1); // 14
  b118->addAction(Supla::TURN_ON , r115, Supla::ON_CLICK_1); // 15
  b118->addAction(Supla::TURN_ON , r116, Supla::ON_CLICK_1); // 16
  b118->addAction(Supla::TURN_ON , r117, Supla::ON_CLICK_1); // 17
  b118->addAction(Supla::TURN_ON , r118, Supla::ON_CLICK_1); // 18

  b118->addAction(Supla::TURN_OFF , r101, Supla::ON_CLICK_2); // 1
  b118->addAction(Supla::TURN_OFF , r102, Supla::ON_CLICK_2); // 2
  b118->addAction(Supla::TURN_OFF , r103, Supla::ON_CLICK_2); // 3
  b118->addAction(Supla::TURN_OFF , r104, Supla::ON_CLICK_2); // 4
  b118->addAction(Supla::TURN_OFF , r105, Supla::ON_CLICK_2); // 5
  b118->addAction(Supla::TURN_OFF , r106, Supla::ON_CLICK_2); // 6
  b118->addAction(Supla::TURN_OFF , r107, Supla::ON_CLICK_2); // 7
  b118->addAction(Supla::TURN_OFF , r108, Supla::ON_CLICK_2); // 8
  b118->addAction(Supla::TURN_OFF , r109, Supla::ON_CLICK_2); // 9
  b118->addAction(Supla::TURN_OFF , r110, Supla::ON_CLICK_2); // 10
  b118->addAction(Supla::TURN_OFF , r111, Supla::ON_CLICK_2); // 11
  b118->addAction(Supla::TURN_OFF , r112, Supla::ON_CLICK_2); // 12
  b118->addAction(Supla::TURN_OFF , r113, Supla::ON_CLICK_2); // 13
  b118->addAction(Supla::TURN_OFF , r114, Supla::ON_CLICK_2); // 14
  b118->addAction(Supla::TURN_OFF , r115, Supla::ON_CLICK_2); // 15
  b118->addAction(Supla::TURN_OFF , r116, Supla::ON_CLICK_2); // 16
  b118->addAction(Supla::TURN_OFF , r117, Supla::ON_CLICK_2); // 17
  b118->addAction(Supla::TURN_OFF , r118, Supla::ON_CLICK_2); // 18
  
  /*
     Having your device already registered at cloud.supla.org,
     you want to change CHANNEL sequence or remove any of them,
     then you must also remove the device itself from cloud.supla.org.
     Otherwise you will get "Channel conflict!" error.
  */
  
  /*
     SuplaDevice Initialization.
     Server address is available at https://cloud.supla.org
     If you do not have an account, you can create it at
     https://cloud.supla.org/account/create SUPLA and SUPLA CLOUD are free of
     charge

  */

  SuplaDevice.begin(
      GUID,              // Global Unique Identifier
      "svrXX.supla.org",  // SUPLA server address
      "user@email.com",   // Email address used to login to Supla Cloud
      AUTHKEY);          // Authorization key
}

void loop() {
  SuplaDevice.iterate();
}
